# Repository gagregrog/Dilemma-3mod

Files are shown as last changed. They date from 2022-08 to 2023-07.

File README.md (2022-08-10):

# Dilemma keyboard

A vertical stagger low-profile keyboard with mods.



- [Dilemma keyboard](#dilemma-keyboard)
  - [Features](#features)
  - [Versions](#versions)
  - [Wireless abilities](#wireless-abilities)
  - [BOM](#bom)
    - [DIY version](#diy-version)
    - [Assembled version](#assembled-version)
    - [Trackpad mod](#trackpad-mod)
    - [3d printed thin case](#3d-printed-thin-case)
    - [3d printed less-thin case with tenting pucks](#3d-printed-less-thin-case-with-tenting-pucks)
  - [Build guide](#build-guide)
  - [Support me on patreon](#support-me-on-patreon) 
  - [Others / in progress](#others--in-progress)

## Features

- Heavy pinky stagger
- MX and choc compatible
- Reversible PCB
- Elite-pi / Splinky / Nice!Nano compatible
- Tenting puck footprint

## Versions

There are 2 versions of the dilemma, in 2 folders:

- `dilemma`, for DIY that requires an additional MCU (eg. kb2040)
- `dilemma_assembled`, for PCB assembly

The Dilemma is **made for rp2040**, so if you go with the DIY version you should source your MCU board accordingly.

## Wireless abilities

ZMK does not support input devices at the moment, and QMK does not support BLE.

However, as this is meant to be a portable keyboard, some ground work has been laid with the DIY version:

- pinout compatible with nice!nano
- 2 battery connectors footprints: JST, and THT
- on / off button footprint

At this time, the assembled version does not support wireless.

## BOM

The PCB can work on standalone.

Depending on which version you go with, you will need to source different items.

On top of the basic build, you can add a range of options, which require additional components:

- 3d printed case
- mods (eg. trackpad)

Both versions of the Dilemma require:

| Part name | Amount | Link / source |
| --- | --- | --- |
| Audio jack | 2 | |
| Button, 4x4x1.5 | 2 | |

### DIY version

On top of the parts mentioned above, you will need:

| Part name | Amount | Link / source |
| --- | --- | --- |
| SOD123 Diodes | 34 | Farnell, Mouser, Aliexpress |
| Dilemma PCB, DIY, 1.2mm | 2 | See Release section |
| RP2040 MCU board | 2 | KB2040, elite-pi... |
| Header pins | 2*12 | |

Please note, **the Dilemma is compatible only with rp2040 boards !**

The release section contains the latest gerbers.

Order in 1.2mm thickness.

### Assembled version



On top of the parts mentioned above, you will need:

| Part name | Amount | Link / source |
| --- | --- | --- |
| Dilemma PCB, assembled, 1.2mm | 2 | See Release section |

The release section contains the latest gerbers with BOM and POS files.

Order in 1.2mm thickness.

### Trackpad mod



This is the first mod made for the keyboard - so it can function as a standalone input device.

It uses I2C on the DIY version, and SPI on the assembled version.

The DIY version requires removing 2 resistors from the trackpad (see build guide).

When installing the trackpad mod, you will need:

| Part name | Amount | Link / source |
| --- | --- | --- |
| M3 screw, torx, 6mm | 4 | Conrad |
| M3x5x5 screw insert | 4 | Aliexpress |
| 3d printed parts | | See `mechanical` folder |

If building the PCBA version, you will also need:

| Part name | Amount | Link / source |
| --- | --- | --- |
| 12-position FPC cable, 0.5mm pitch, same side contacts, 100mm | 1 | Farnell |

If building the DIY version, you will also need:

| Part name | Amount | Link / source |
| --- | --- | --- |
| SOD123 Resistor, 5kOhms | 2 | |
| Cables | | |

### 3d printed thin case

Designed for the minimum footprint possible, while still protecting the PCB.

| Part name | Amount | Link / source |
| --- | --- | --- |
| M3 screw, torx, 6mm | 6 | Conrad |
| M3 nut | 3 | Conrad |
| Anti slip pads, 10x2mm | 12 | Aliexpress |
| 3d case | 1 right, 1 left | See `mechanical` folder |

The case is reversible.

It needs to be printed at 0.2mm layer height supportless specifically for the nut inserts suport-less interfaces. If you are doing a different layer height, use supports. 

### 3d printed less-thin case with tenting pucks

Accomodates the Splitkb tenting puck, to be used with a Manfrotto tripod.



BOM:

| Part name | Amount | Link / source |
| --- | --- | --- |
| M3 screw, torx, 6mm | 6 | Conrad |
| M3 nut | 3 | Conrad |
| Anti slip pads, 10x2mm | 12 | Aliexpress |
| Tenting puck assembly  | 1 | Splitkb |
| Manfrotto tripod | 2 | Manfrotto |
| 3d case | 1 right, 1 left | See `mechanical` folder |

The case is reversible.

It needs to be printed at 0.2mm layer height supportless specifically for the nut inserts suport-less interfaces. If you are doing a different layer height, use supports.

## Build guide

https://docs.bastardkb.com/hc/en-us/sections/6848232395410-Dilemma

## Support me on Patreon

If you like the keyboard, please consider helping me with Patreon: https://www.patreon.com/bastardkb

I post regular updates and hindsight on my work. I work full time on keyboard innovation, and this helps a lot !

## Others / in progress

The PCB has available connectors for:

- oled

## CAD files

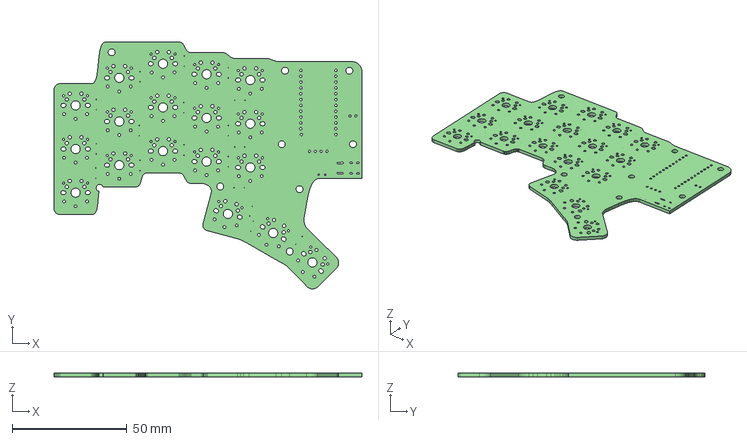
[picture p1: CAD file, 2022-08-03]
mechanical/3mod physical design/dilemma_3mod_pcb.step
134.0 x 107.4 x 1.60 mm

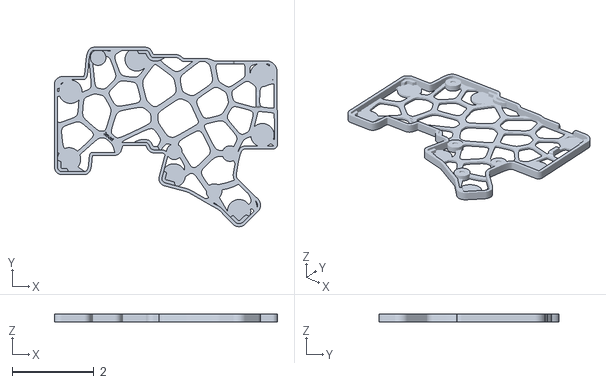
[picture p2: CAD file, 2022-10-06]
mechanical/cases/thin/3mod_thin_v1.stl
5.45 x 4.39 x 0.193

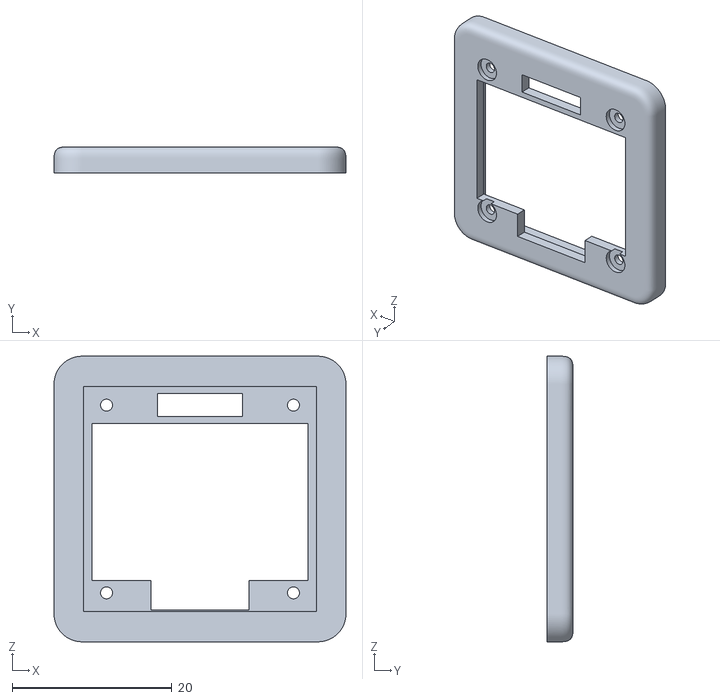
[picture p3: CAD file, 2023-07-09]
mechanical/handwire_mod/0.96_in_oled_holder/oled_holder_top.stl
36.5 x 3.27 x 35.7

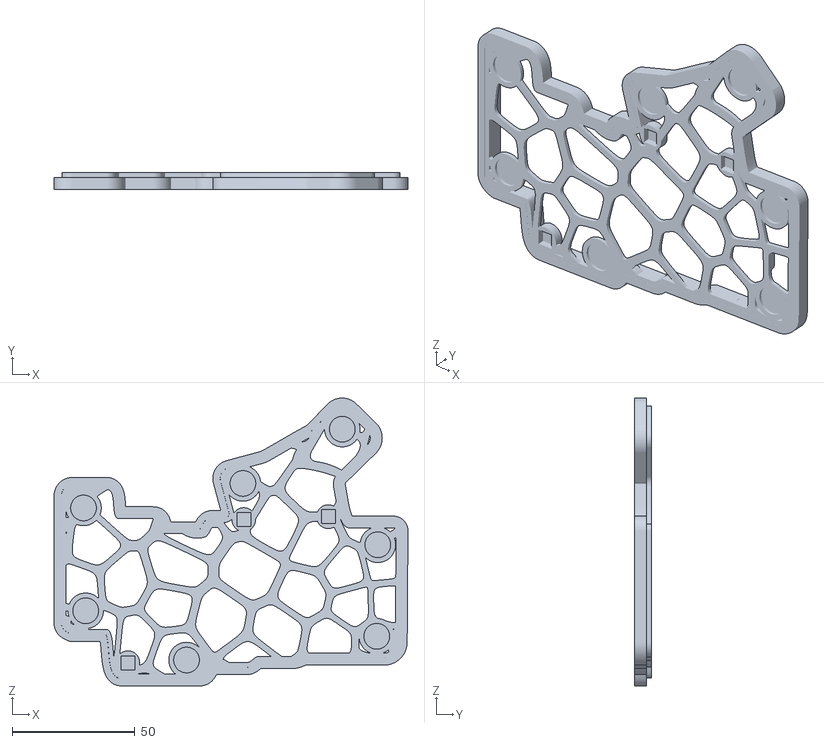
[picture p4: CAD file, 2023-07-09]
mechanical/handwire_mod/case/left/dilemma_hand_wire_left_bottom_v1.stl
144.3 x 6.90 x 117.4

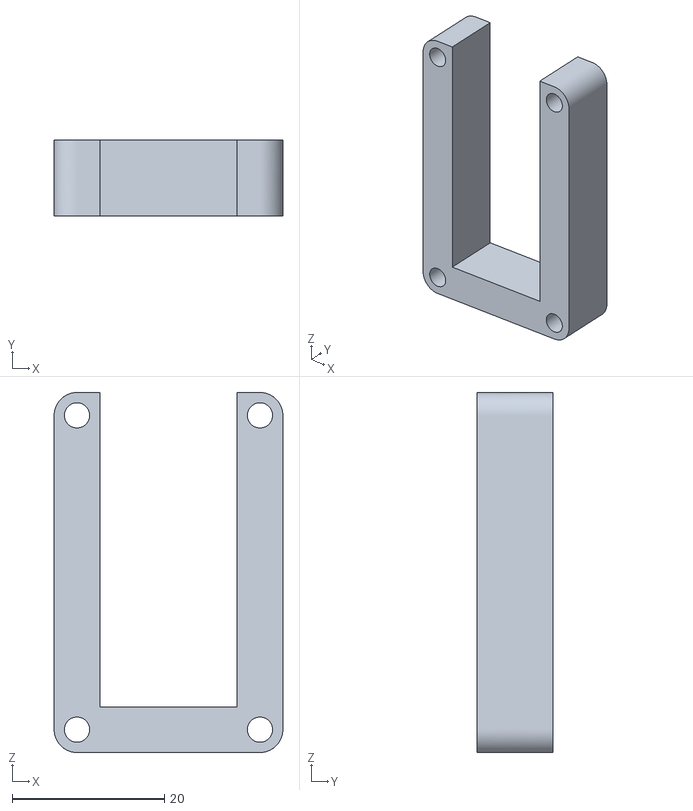
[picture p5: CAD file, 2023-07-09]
mechanical/handwire_mod/cirque_35/circue_35_bottom_v1.stl
30.0 x 10.0 x 47.2

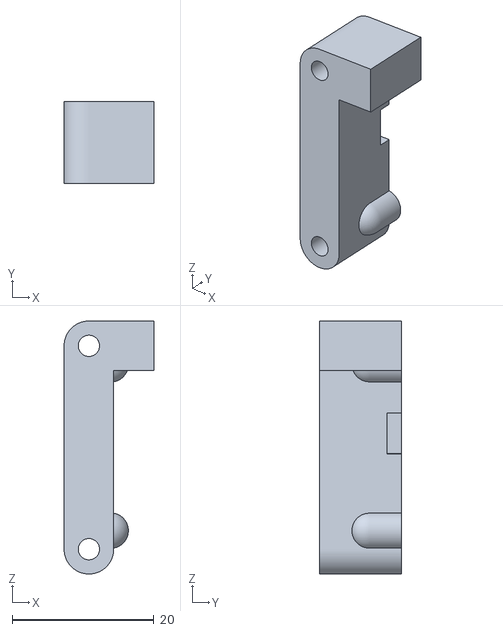
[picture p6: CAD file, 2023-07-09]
mechanical/handwire_mod/0.96_in_oled_holder/oled_holder_bottom_left.stl
12.7 x 11.5 x 35.7

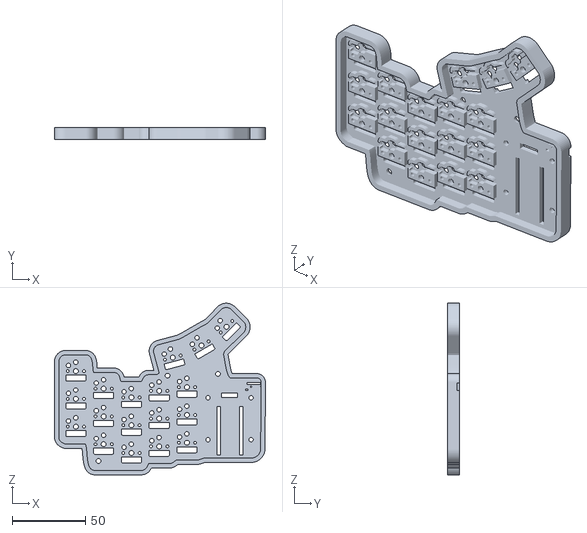
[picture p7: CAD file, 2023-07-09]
mechanical/handwire_mod/case/left/dilemma_hand_wire_left_top_v1.stl
144.3 x 7.90 x 117.4

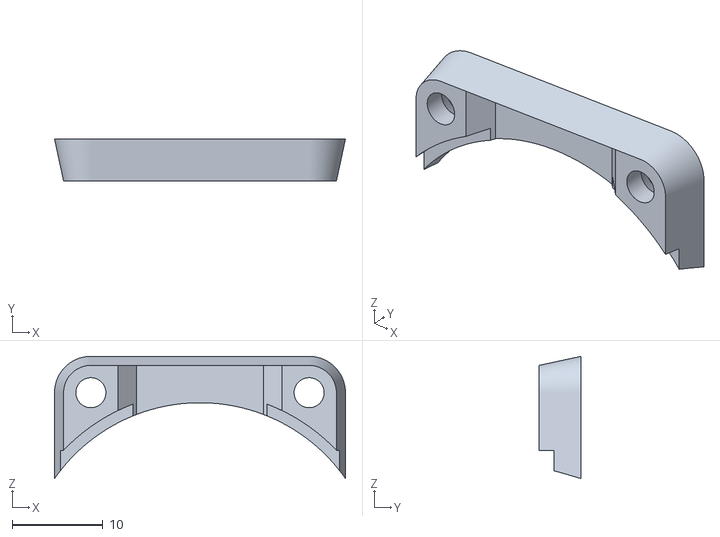
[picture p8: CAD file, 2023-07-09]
mechanical/handwire_mod/cirque_35/cirque_35_top_back_v1.stl
32.0 x 4.65 x 13.5

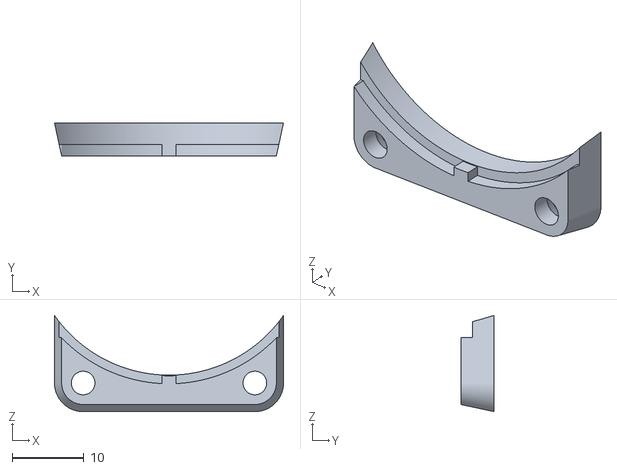
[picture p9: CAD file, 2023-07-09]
mechanical/handwire_mod/cirque_35/cirque_35_top_front_v1.stl
32.0 x 4.65 x 13.5

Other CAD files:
mechanical/handwire_mod/case/right/dilemma_hand_wire_right_bottom_v1.stl
mechanical/handwire_mod/case/right/dilemma_hand_wire_right_top_v1.stl
mechanical/handwire_mod/0.96_in_oled_holder/oled_holder_bottom_right.stl

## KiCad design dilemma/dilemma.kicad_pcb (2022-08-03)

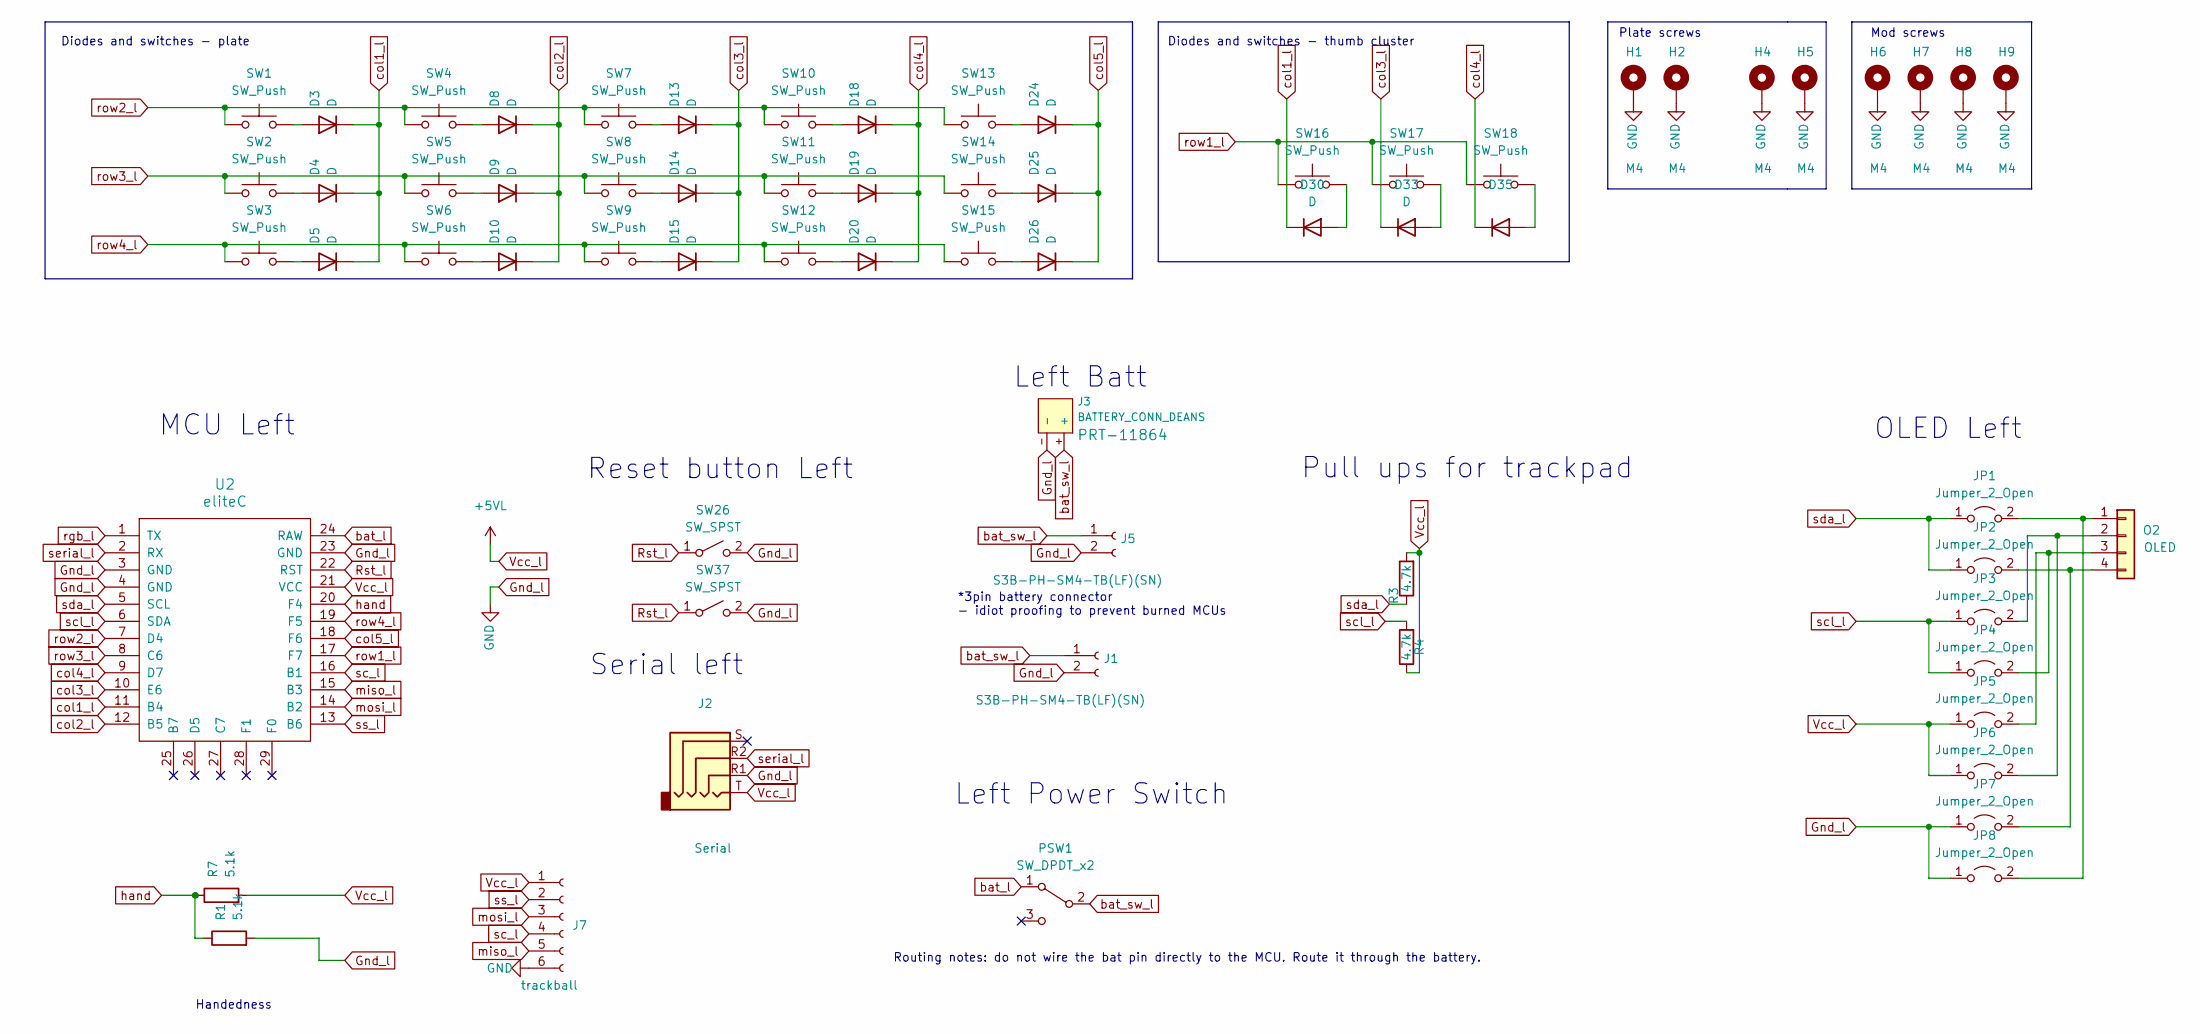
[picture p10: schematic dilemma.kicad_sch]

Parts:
D3, D4, D5, D8, D9, D10, D13, D14, D15, D18, D19, D20, D24, D25, D26, D30, D33: D
D35: (no value)
H1, H2, H4, H5, H6, H7, H8, H9: M4; MountingHole_3mm_Pad_thin
J1, J5: S3B-PH-SM4-TB(LF)(SN); JST_SH_BM02B-SRSS-TB_1x02-1MP_P1.00mm_Vertical; LCSC C265101
J2: Serial; Jack_3.5mm_PJ320E_Horizontal_reversible
J3: BATTERY_CONN_DEANS; battery_connector_THT
J7: trackball; 6_PinHeader
JP1, JP2, JP3, JP4, JP5, JP6, JP7, JP8: Jumper_2_Open; SolderJumper-2_P1.3mm_Open_RoundedPad1.0x1.5mm
O2: OLED; PinHeader_1x04_P2.54mm_Vertical
PSW1: SW_DPDT_x2; Switch_MSK-12C01-07; LCSC C431540
R1, R7: 5.1k; R_1206_handsolder; JLCPCB BOM 1
R3, R4: 4.7k; R_1206_handsolder_reversible; LCSC C269746
SW1, SW2, SW3, SW4, SW5, SW6, SW7, SW8, SW9, SW10, SW11, SW12, SW13, SW14, SW15, SW16, SW17, SW18: SW_Push; SW_MX_choc
SW26, SW37: SW_SPST; SW_Push_1P1T_NO_6x6mm_H9.5mm
U2: eliteC; pro-micro

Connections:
Gnd_l: H1.1, H2.1, H4.1, H5.1, H6.1, H7.1, H8.1, H9.1, J1.2, J2.R1, J3.-, J5.2, J7.6, JP7.1 (A), JP8.1 (A), R1.2, SW26.2 (B), SW37.2 (B), U2.3 (GND), U2.4 (GND), U2.23 (GND); also elsewhere on the board
unnamed: D3.2 (A), SW1.2
unnamed: D4.2 (A), SW2.2
unnamed: D5.2 (A), SW3.2
unnamed: D8.2 (A), SW4.2
unnamed: D9.2 (A), SW5.2
unnamed: D10.2 (A), SW6.2
unnamed: D13.2 (A), SW7.2
unnamed: D14.2 (A), SW8.2
unnamed: D15.2 (A), SW9.2
unnamed: D18.2 (A), SW10.2
unnamed: D19.2 (A), SW11.2
unnamed: D20.2 (A), SW12.2
unnamed: D24.2 (A), SW13.2
unnamed: D25.2 (A), SW14.2
unnamed: D26.2 (A), SW15.2
unnamed: D30.2 (A), SW16.2
unnamed: D33.2 (A), SW17.2
unnamed: D35.2 (A), SW18.2
unnamed: JP1.2 (B), JP8.2 (B), O2.1
unnamed: JP2.2 (B), JP7.2 (B), O2.4
unnamed: JP3.2 (B), JP6.2 (B), O2.2
unnamed: JP4.2 (B), JP5.2 (B), O2.3
Rst_l: SW26.1 (A), SW37.1 (A), U2.22 (RST)
Vcc_l: J2.T, J7.1, JP5.1 (A), JP6.1 (A), R3.2, R4.1, R7.2, U2.21 (VCC)
bat_l: PSW1.1 (A), U2.24 (RAW)
bat_sw_l: J1.1, J3.+, J5.1, PSW1.2 (B)
col1_l: D3.1 (K), D4.1 (K), D5.1 (K), D30.1 (K), U2.11 (B4)
col2_l: D8.1 (K), D9.1 (K), D10.1 (K), U2.12 (B5)
col3_l: D13.1 (K), D14.1 (K), D15.1 (K), D33.1 (K), U2.10 (E6)
col4_l: D18.1 (K), D19.1 (K), D20.1 (K), D35.1 (K), U2.9 (D7)
col5_l: D24.1 (K), D25.1 (K), D26.1 (K), U2.18 (F6)
hand: R1.1, R7.1, U2.20 (F4)
miso_l: J7.5, U2.15 (B3)
mosi_l: J7.3, U2.14 (B2)
rgb_l: U2.1 (TX)
row1_l: SW16.1, SW17.1, SW18.1, U2.17 (F7)
row2_l: SW1.1, SW4.1, SW7.1, SW10.1, SW13.1, U2.7 (D4)
row3_l: SW2.1, SW5.1, SW8.1, SW11.1, SW14.1, U2.8 (C6)
row4_l: SW3.1, SW6.1, SW9.1, SW12.1, SW15.1, U2.19 (F5)
sc_l: J7.4, U2.16 (B1)
scl_l: JP3.1 (A), JP4.1 (A), R4.2, U2.6 (SDA)
sda_l: JP1.1 (A), JP2.1 (A), R3.1, U2.5 (SCL)
serial_l: J2.R2, U2.2 (RX)
ss_l: J7.2, U2.13 (B6)

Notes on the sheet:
MCU Left
Left Batt
Handedness
Plate screws
Routing notes: do not wire the bat pin directly to the MCU. Route it through the battery.
Serial left
Diodes and switches - plate
Reset button Left
Pull ups for trackpad
Mod screws
Left Power Switch
OLED Left
Diodes and switches - thumb cluster
*3pin battery connector - idiot proofing to prevent burned MCUs

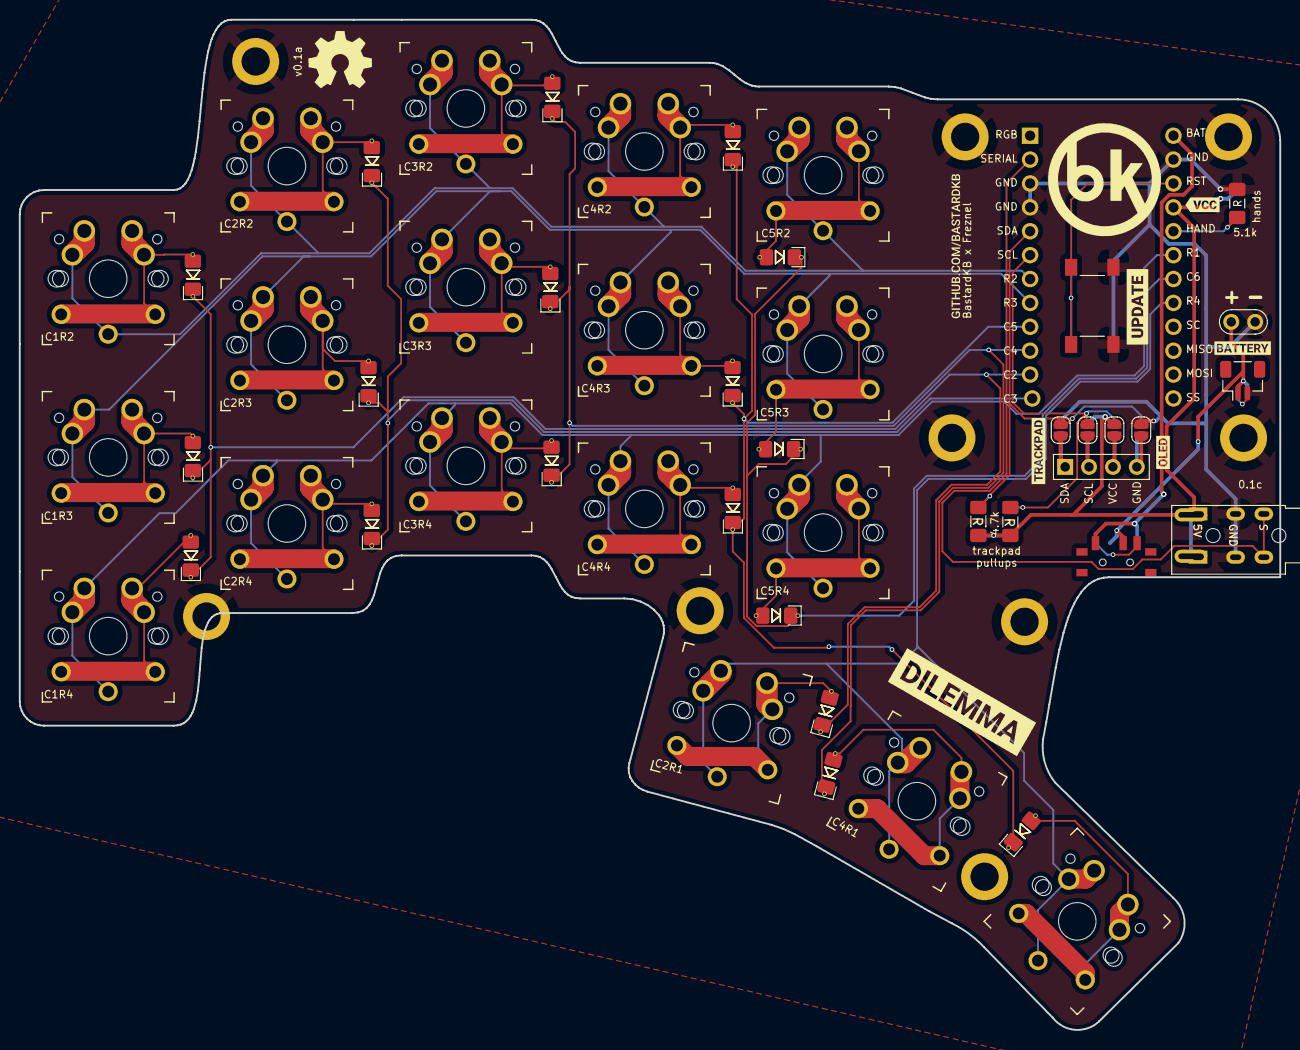
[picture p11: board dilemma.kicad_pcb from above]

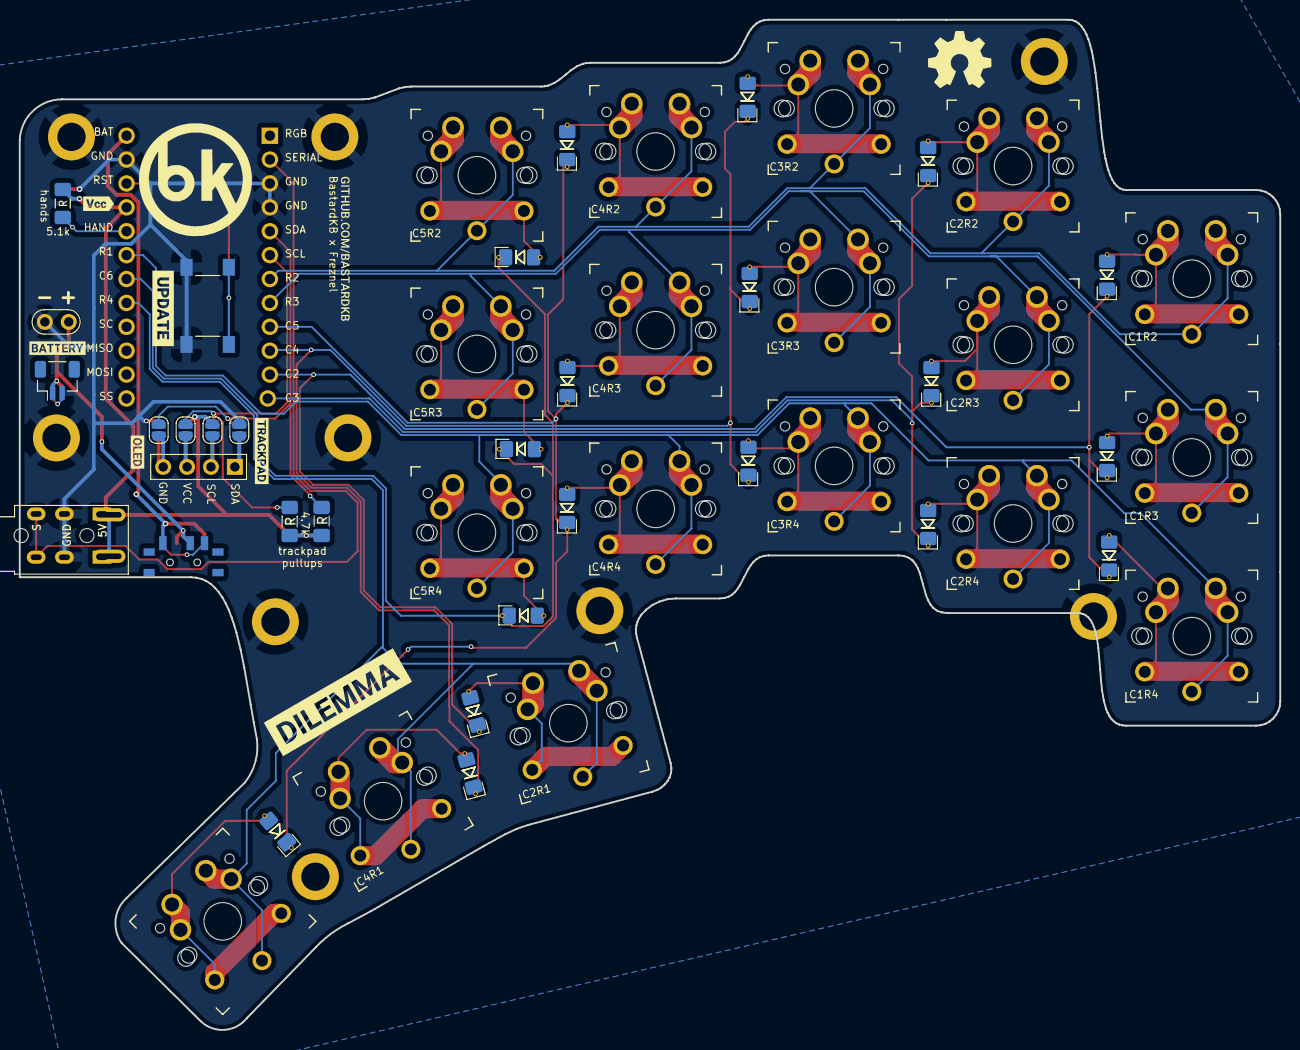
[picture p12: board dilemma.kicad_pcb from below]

Board: 2 copper layers, 134.0 x 107.4 mm, 80 parts (15 on the bottom side), 40 nets.

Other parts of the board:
H2#2: M4; MountingHole_3mm_Pad_thin
kibuzzard-61F01A92, kibuzzard-61F01A92#2: G***; kibuzzard-61F01A92
kibuzzard-61F01C84, kibuzzard-61F01C84#2: G***; kibuzzard-61F01C84
kibuzzard-628D3AA1: G***; kibuzzard-628D3AA1
kibuzzard-628D396A: G***; kibuzzard-628D396A
kibuzzard-628DFB5F, kibuzzard-628DFB5F#2: G***; kibuzzard-628DFB5F
kibuzzard-628DFB48, kibuzzard-628DFB48#2: G***; kibuzzard-628DFB48
kibuzzard-628DFB95, kibuzzard-628DFB95#2: G***; kibuzzard-628DFB95
kibuzzard-628E0199, kibuzzard-628E0199#2: G***; kibuzzard-628E0199

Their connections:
Gnd_l: H2#2.1; also elsewhere on the board

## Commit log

2022-07-27 added third thumb key in schematic and pcb layout
    firmware not touched yet, case and supporting objects not touched yet, gerbers expored in the dilemma subfolder
    [dilemma.kicad_pcb, dilemma.kicad_sch]
2022-08-03 mostly step and organization
    [dilemma.kicad_pcb, dilemma_3mod_pcb.step]
2022-08-10 pull from main branch
    [dilemma.kicad_sch]
2022-10-06 add modified thin case for 3mod
    [3mod_thin_v1.stl]
2023-07-09 feat: handwire v1
    [circue_35_bottom_v1.stl, cirque_35_top_back_v1.stl, cirque_35_top_front_v1.stl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]

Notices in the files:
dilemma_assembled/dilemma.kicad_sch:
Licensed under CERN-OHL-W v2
